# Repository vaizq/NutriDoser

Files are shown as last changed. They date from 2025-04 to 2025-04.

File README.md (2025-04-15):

# NutriDoser - Modular nutrient and pH controller for hydroponics

**NutriDoser** is and open-source prototype of an modular and extensible hydroponics reservoir controller.
Most devices on the market have limited capabilites on the number of nutrients that can be scheduled, but there's no limit with NutriDoser.
**DoserModules** can be daisy chained and controller detects how many of these modules there are and a scheduler takes care that no more than **n** parallel dosers are running.

> ⚠️ **Disclaimer:** This project is still at prototyping stage and should not be used without supervising.
 
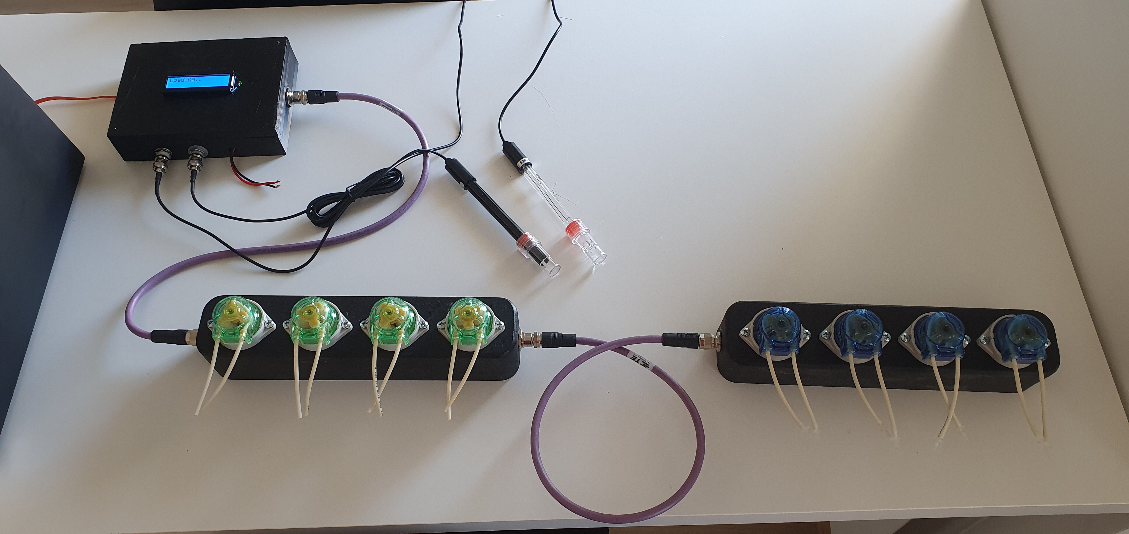
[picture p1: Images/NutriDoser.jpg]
NutriDoser

DoserModule pcb

---

## ✨ Key Features

- **Connect unlimited number of dosing pumps**
- **Web interface**
- **Custom PCB that's designed to use mostly basic parts from JLCPCB**
- **Automatic CAN termination**

---

## 🌐 Demo video
https://youtu.be/jbT3SvvVrZw

---

## ⚙️ Stack

- **C++** – Embedded code
- **Javascript + React** – Web interface
- **KiCad** – Hardware design
- **ESP32**
- **STM32**

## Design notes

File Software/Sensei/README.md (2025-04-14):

# Sensei - Heart of hydroponics reservoir automation

## Features
- Read pH and EC sensors
- Control NutriDosers trough DoserManager api
- LCD display
- Automatic controllers for pH and nutrients
- Wifi provisioning
- mqtt api

## Missing features

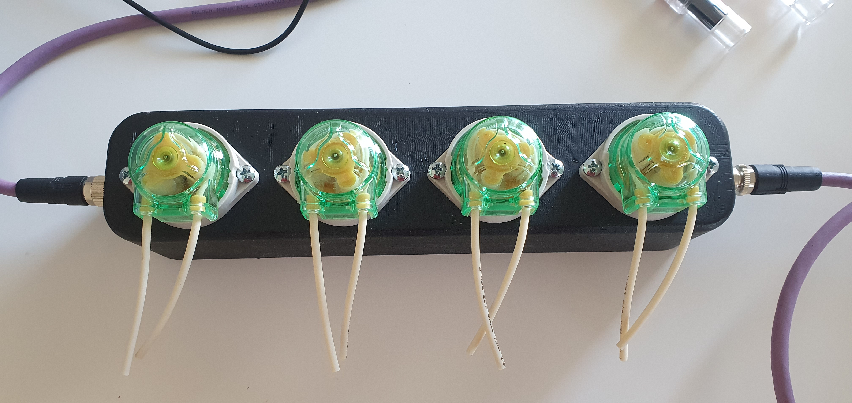
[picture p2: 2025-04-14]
Images/doserModule.jpg

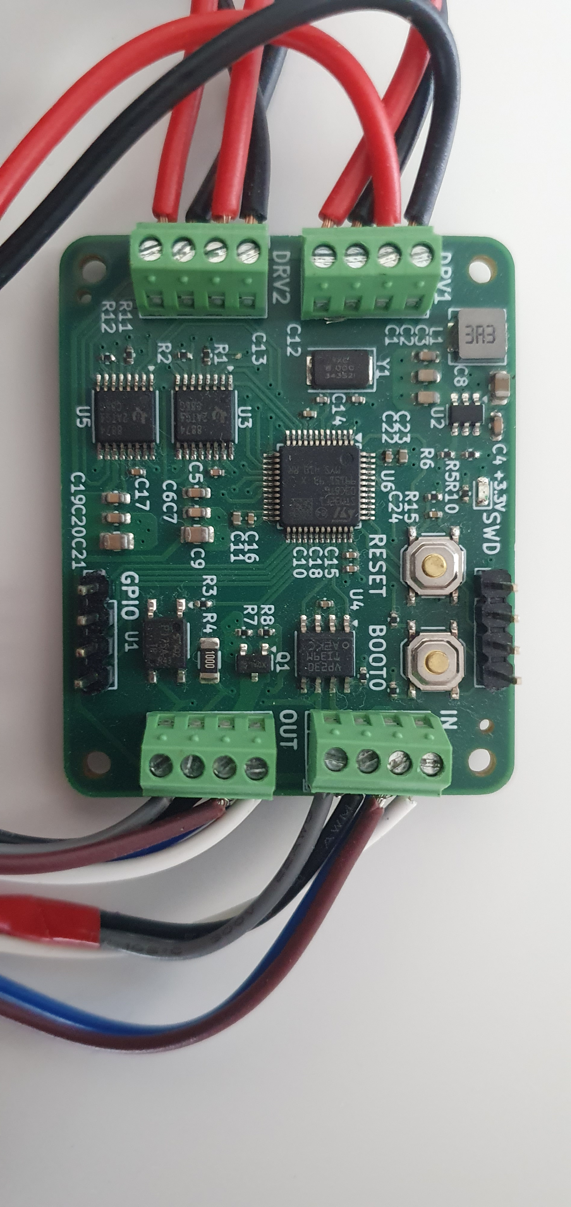
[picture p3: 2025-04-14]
Images/pcb.jpg

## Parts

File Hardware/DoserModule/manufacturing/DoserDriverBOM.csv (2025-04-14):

Comment | Designator | Footprint | LCSC
10uF | C1,C2 | Capacitor_SMD:C_0603_1608Metric | C96446
100nF | C10,C13,C15,C16,C18,C22,C24 | Capacitor_SMD:C_0402_1005Metric | C1525
10uF | C11,C23 | Capacitor_SMD:C_0402_1005Metric | C15525
30pF | C12,C14 | Capacitor_SMD:C_0402_1005Metric | C1570
100nF | C3,C4,C6,C7,C19,C20 | Capacitor_SMD:C_0603_1608Metric | C14663
22nF | C5,C17 | Capacitor_SMD:C_0402_1005Metric | C1532
47uF | C8 | Capacitor_SMD:C_0805_2012Metric | C16780
22uF | C9,C21 | Capacitor_SMD:C_0805_2012Metric | C45783
LED_Small | D1 | LED_SMD:LED_0603_1608Metric | C2286
3.3uH | L1 | Inductor_SMD:L_Sunlord_MWSA0402S | C408336
AO3400A | Q1 | Package_TO_SOT_SMD:SOT-23 | C20917
10kOhm | R1,R6,R11,R13,R14,R15 | Resistor_SMD:R_0402_1005Metric | C25744
1k5 Ohm | R10 | Resistor_SMD:R_0402_1005Metric | C25867
4.7kOhm | R2,R12 | Resistor_SMD:R_0402_1005Metric | C25900
470 Ohm | R3,R8 | Resistor_SMD:R_0402_1005Metric | C25117
100 Ohm | R4 | Resistor_SMD:R_1206_3216Metric | C17901
33.2kOhm | R5 | Resistor_SMD:R_0402_1005Metric | C122548
47kOhm | R7,R9 | Resistor_SMD:R_0402_1005Metric | C25792
SW_Push | SW1,SW2 | AutoDoser:SW_Push_1P1T_XKB_TS-1187A | C318884
TLP175A | U1 | Package_SO:MFSOP6-4_4.4x3.6mm_P1.27mm | C141522
TPS561208 | U2 | Package_TO_SOT_SMD:SOT-23-6 | C138335
DRV8874 | U3,U5 | AutoDoser:HTSSOP-16-1EP_4.4x5mm_P0.65mm_EP3.4x5mm_Mask2.46x2.31mm | C1855818
SN65HVD230 | U4 | Package_SO:SOIC-8_3.9x4.9mm_P1.27mm | C12084
STM32F103C8Tx | U6 | Package_QFP:LQFP-48_7x7mm_P0.5mm | C8734
Crystal | Y1 | Crystal:Crystal_SMD_5032-2Pin_5.0x3.2mm | C115962

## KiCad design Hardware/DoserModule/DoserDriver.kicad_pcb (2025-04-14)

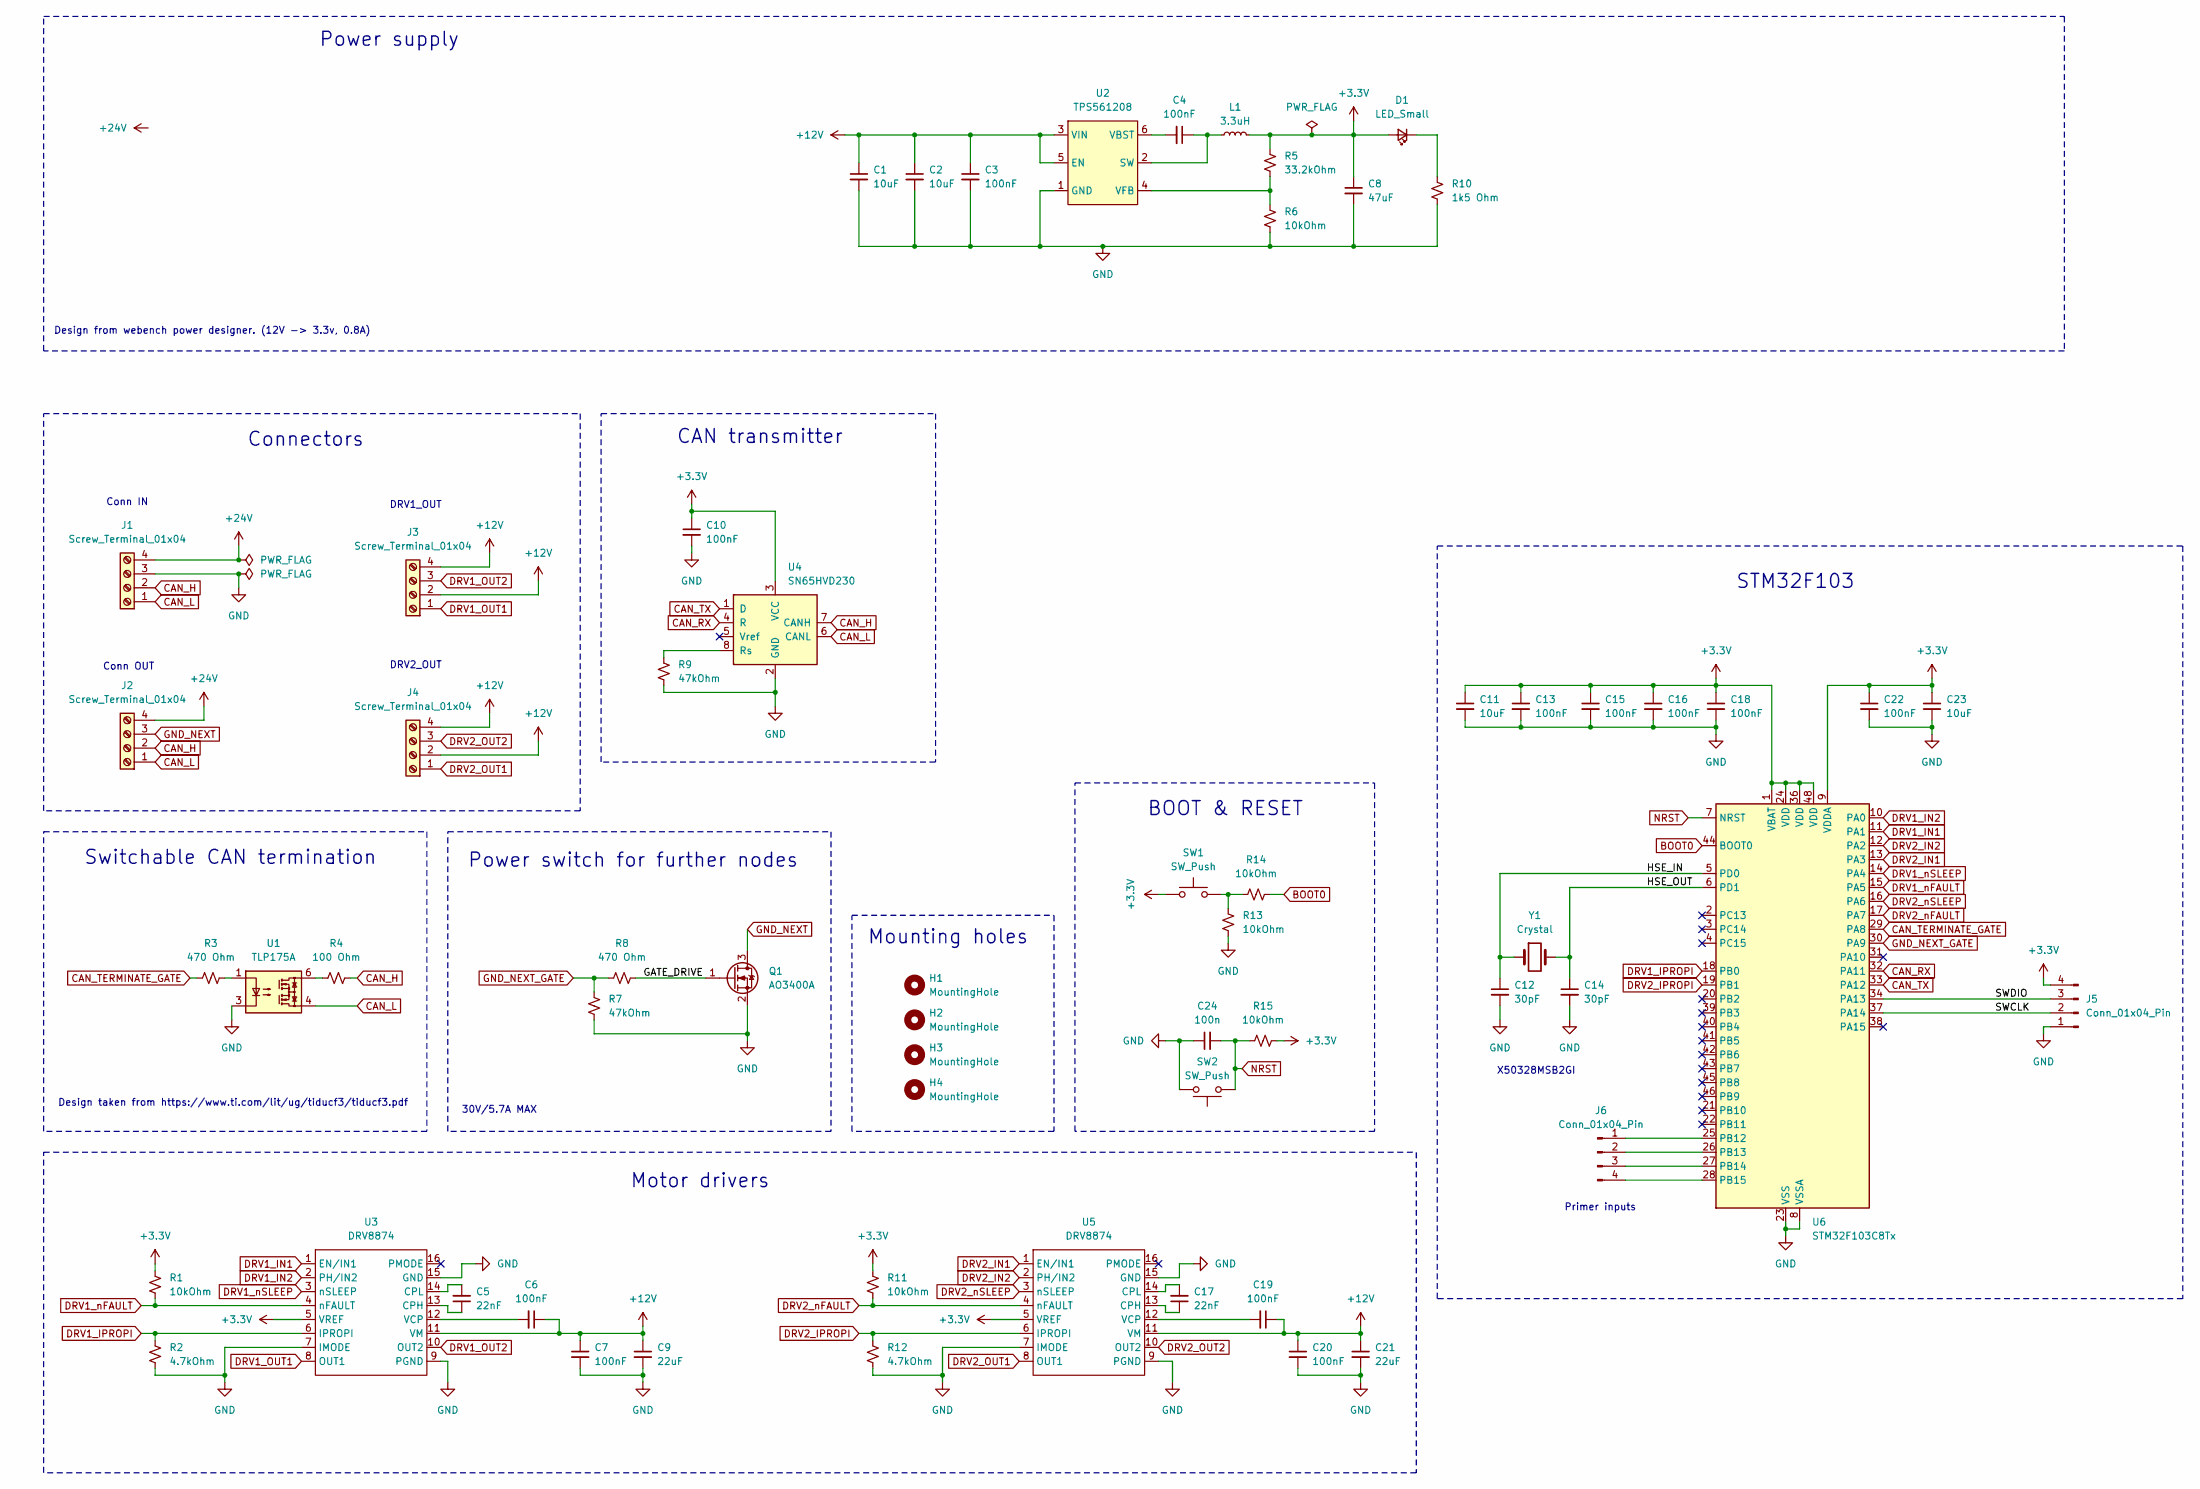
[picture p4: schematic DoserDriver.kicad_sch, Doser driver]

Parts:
C1, C2: 10uF; C_0603_1608Metric
C3, C4, C6, C7, C19, C20: 100nF; C_0603_1608Metric
C5, C17: 22nF; C_0402_1005Metric
C8: 47uF; C_0805_2012Metric
C9, C21: 22uF; C_0805_2012Metric
C10, C13, C15, C16, C18, C22: 100nF; C_0402_1005Metric
C11, C23: 10uF; C_0402_1005Metric
C12, C14: 30pF; C_0402_1005Metric
C24: 100n; C_0402_1005Metric
D1: LED_Small; LED_0603_1608Metric
H1, H2, H3, H4: MountingHole; MountingHole_2.2mm_M2
J1, J2, J3, J4: Screw_Terminal_01x04; TerminalBlock_Xinya_XY308-2.54-4P_1x04_P2.54mm_Horizontal
J5, J6: Conn_01x04_Pin; PinHeader_1x04_P2.54mm_Vertical
L1: 3.3uH; L_Sunlord_MWSA0402S
Q1: AO3400A; SOT-23
R1, R6, R11, R13, R14, R15: 10kOhm; R_0402_1005Metric
R2, R12: 4.7kOhm; R_0402_1005Metric
R3, R8: 470 Ohm; R_0402_1005Metric
R4: 100 Ohm; R_1206_3216Metric
R5: 33.2kOhm; R_0402_1005Metric
R7, R9: 47kOhm; R_0402_1005Metric
R10: 1k5 Ohm; R_0402_1005Metric
SW1, SW2: SW_Push; SW_Push_1P1T_XKB_TS-1187A
U1: TLP175A; MFSOP6-4_4.4x3.6mm_P1.27mm
U2: TPS561208; SOT-23-6
U3, U5: DRV8874; HTSSOP-16-1EP_4.4x5mm_P0.65mm_EP3.4x5mm_Mask2.46x2.31mm
U4: SN65HVD230; SOIC-8_3.9x4.9mm_P1.27mm
U6: STM32F103C8Tx; LQFP-48_7x7mm_P0.5mm
Y1: Crystal; Crystal_SMD_5032-2Pin_5.0x3.2mm

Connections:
+3.3V: C8.1, C10.1, C11.1, C13.1, C15.1, C16.1, C18.1, C22.1, C23.1, D1.2 (A), J5.4, L1.2, R1.1, R5.1, R11.1, R15.2, SW1.1, U3.5 (VREF), U4.3 (VCC), U5.5 (VREF), U6.1 (VBAT), U6.9 (VDDA), U6.24 (VDD), U6.36 (VDD), U6.48 (VDD)
/GATE_DRIVE: Q1.1 (G), R8.2
/HSE_IN: C12.1, U6.5 (PD0), Y1.1
/HSE_OUT: C14.1, U6.6 (PD1), Y1.2
/SWCLK: J5.2, U6.37 (PA14)
/SWDIO: J5.3, U6.34 (PA13)
BOOT0: R14.2, U6.44 (BOOT0)
CAN_H: J1.2, J2.2, R4.2, U4.7 (CANH)
CAN_L: J1.1, J2.1, U1.4, U4.6 (CANL)
CAN_RX: U4.4 (R), U6.32 (PA11)
CAN_TERMINATE_GATE: R3.2, U6.29 (PA8)
CAN_TX: U4.1 (D), U6.33 (PA12)
DRV1_IN1: U3.1 (EN/IN1), U6.11 (PA1)
DRV1_IN2: U3.2 (PH/IN2), U6.10 (PA0)
DRV1_IPROPI: R2.1, U3.6 (IPROPI), U6.18 (PB0)
DRV1_OUT1: J3.1, U3.8 (OUT1)
DRV1_OUT2: J3.3, U3.10 (OUT2)
DRV1_nFAULT: R1.2, U3.4 (nFAULT), U6.15 (PA5)
DRV1_nSLEEP: U3.3 (nSLEEP), U6.14 (PA4)
DRV2_IN1: U5.1 (EN/IN1), U6.13 (PA3)
DRV2_IN2: U5.2 (PH/IN2), U6.12 (PA2)
DRV2_IPROPI: R12.1, U5.6 (IPROPI), U6.19 (PB1)
DRV2_OUT1: J4.1, U5.8 (OUT1)
DRV2_OUT2: J4.3, U5.10 (OUT2)
DRV2_nFAULT: R11.2, U5.4 (nFAULT), U6.17 (PA7)
DRV2_nSLEEP: U5.3 (nSLEEP), U6.16 (PA6)
GND: C1.2, C2.2, C3.2, C7.2, C8.2, C9.2, C10.2, C11.2, C12.2, C13.2, C14.2, C15.2, C16.2, C18.2, C20.2, C21.2, C22.2, C23.2, C24.1, J1.3, J5.1, Q1.2 (S), R2.2, R6.2, R7.2, R9.1, R10.1, R12.2, R13.2, SW2.2, U1.3, U2.1 (GND), U3.7 (IMODE), U3.9 (PGND), U3.15 (GND), U4.2 (GND), U5.7 (IMODE), U5.9 (PGND), U5.15 (GND), U6.8 (VSSA), U6.23 (VSS), U6.35 (VSS), U6.47 (VSS)
GND_NEXT: J2.3, Q1.3 (D)
GND_NEXT_GATE: R7.1, R8.1, U6.30 (PA9)
NRST: C24.2, R15.1, SW2.1, U6.7 (NRST)
unnamed: D1.1 (K), R10.2
unnamed: J6.1, U6.25 (PB12)
unnamed: J6.2, U6.26 (PB13)
unnamed: J6.3, U6.27 (PB14)
unnamed: J6.4, U6.28 (PB15)
unnamed: R3.1, U1.1
unnamed: R4.1, U1.6
unnamed: R13.1, R14.1, SW1.2
unnamed: C4.1, L1.1, U2.2 (SW)
unnamed: C4.2, U2.6 (VBST)
unnamed: R5.2, R6.1, U2.4 (VFB)
unnamed: C5.1, U3.13 (CPH)
unnamed: C5.2, U3.14 (CPL)
unnamed: C6.2, U3.12 (VCP)
unnamed: R9.2, U4.8 (Rs)
unnamed: C17.1, U5.13 (CPH)
unnamed: C17.2, U5.14 (CPL)
unnamed: C19.2, U5.12 (VCP)

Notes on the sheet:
Conn OUT
Motor drivers
Mounting holes
X50328MSB2GI
Design from webench power designer. (12V -> 3.3v, 0.8A)
BOOT & RESET
30V/5.7A MAX
Connectors
Primer inputs
STM32F103
Conn IN
Switchable CAN termination
Design taken from https://www.ti.com/lit/ug/tiducf3/tiducf3.pdf
CAN transmitter
Power switch for further nodes
DRV1_OUT
Power supply
DRV2_OUT

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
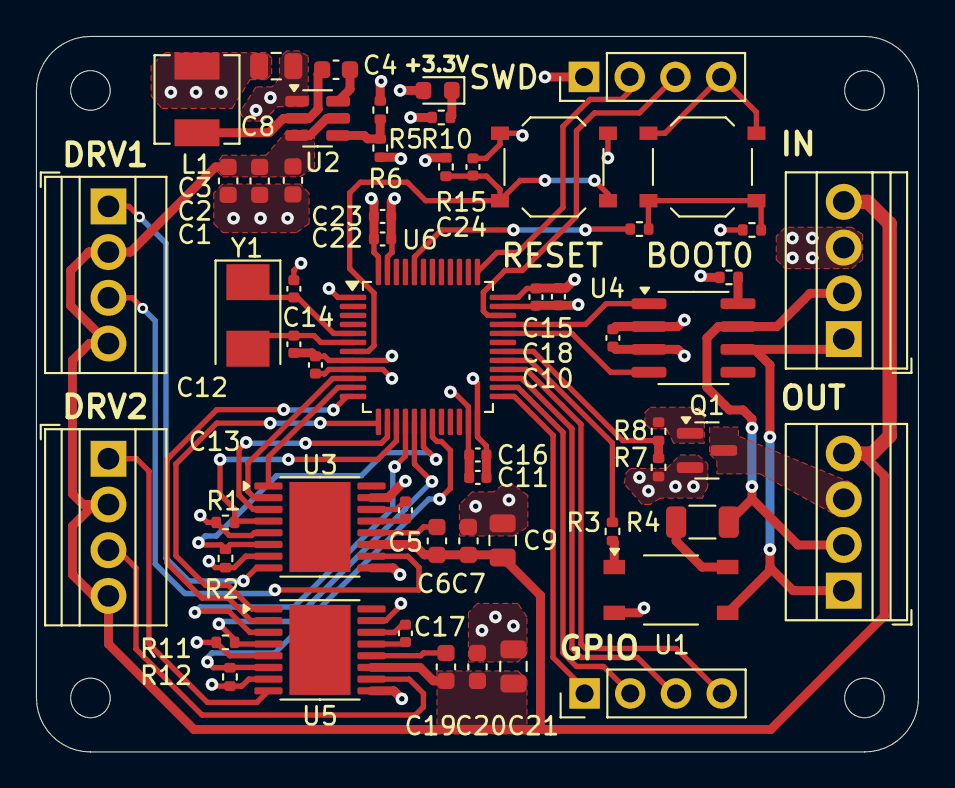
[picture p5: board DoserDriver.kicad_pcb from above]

Board: 4 copper layers, 49.0 x 39.8 mm, 61 parts (0 on the bottom side), 49 nets.

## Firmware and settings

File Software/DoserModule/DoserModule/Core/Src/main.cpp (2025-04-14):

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
/* Includes ------------------------------------------------------------------*/
#include "main.h"

/* USER CODE BEGIN Includes */
#include "app.hpp"
/* USER CODE END Includes */

ADC_HandleTypeDef hadc1;

CAN_HandleTypeDef hcan;

TIM_HandleTypeDef htim1;
TIM_HandleTypeDef htim2;

void SystemClock_Config(void);
static void MX_GPIO_Init(void);
static void MX_ADC1_Init(void);
static void MX_CAN_Init(void);
static void MX_TIM2_Init(void);
static void MX_TIM1_Init(void);
/**
  * @brief  The application entry point.
  * @retval int
  */
int main(void)
{

  /* MCU Configuration--------------------------------------------------------*/

  /* Reset of all peripherals, Initializes the Flash interface and the Systick. */
  HAL_Init();

  /* Configure the system clock */
  SystemClock_Config();

  /* Initialize all configured peripherals */
  MX_GPIO_Init();
  MX_ADC1_Init();
  MX_CAN_Init();
  MX_TIM2_Init();
  MX_TIM1_Init();
  /* USER CODE BEGIN 2 */

  // Start PWM channels
  HAL_TIM_PWM_Start(&htim2, TIM_CHANNEL_1);
  HAL_TIM_PWM_Start(&htim2, TIM_CHANNEL_2);
  HAL_TIM_PWM_Start(&htim2, TIM_CHANNEL_3);
  HAL_TIM_PWM_Start(&htim2, TIM_CHANNEL_4);

  // Start timer2 for steady_clock
  HAL_TIM_Base_Start_IT(&htim1);

  // Terminate CAN
  HAL_GPIO_WritePin(GPIOA, GPIO_PIN_8, GPIO_PIN_SET);

  if (HAL_CAN_Start(&hcan) != HAL_OK) {
      Error_Handler();
  }

  app_main(hcan);

  /* USER CODE END 2 */

  /* Infinite loop */
  /* USER CODE BEGIN WHILE */
  //while (1)
  {
    /* USER CODE END WHILE */

    /* USER CODE BEGIN 3 */
  }
  /* USER CODE END 3 */
}

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


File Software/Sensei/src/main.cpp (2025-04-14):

#include "App.hpp"
#include "mqtt.hpp"
#include <ArduinoJson.h>
#include <cstdio>

std::unique_ptr<App> gApp;

void apiRun() {
  ez::mqtt::Client client{"mqtt://5.61.89.44:1883"};

  client.subscribe("sensei/doser/on", [](const JsonDocument &doc) {
    const int id = doc["doserID"];
    if (auto doser = gDoserManager->lendDoser(id); doser) {
      if (doser->tryOn(doc["flowRate"]))
        gApp->runningDosers.push_back(std::move(*doser));
    }
  });

  client.subscribe("sensei/doser/off", [](const JsonDocument &doc) {
    std::erase_if(gApp->runningDosers,
                  [id = doc["doserID"]](const auto &doser) {
                    return doser.getId() == id;
                  });
  });

  client.subscribe("sensei/doserManager/reset",
                   []() { gApp->runningDosers.clear(); });

  client.subscribe("sensei/pHSensor/calibrate", [](const JsonDocument &doc) {
    gApp->pHSensor->calibrate(doc["target"]);
  });

  client.subscribe("sensei/ecSensor/calibrate", [](const JsonDocument &doc) {
    gApp->ecSensor->calibrate(doc["target"]);
  });

  client.subscribe("sensei/pHSensor/factoryReset",
                   []() { gApp->pHSensor->factoryReset(); });

  client.subscribe("sensei/ecSensor/factoryReset",
                   []() { gApp->ecSensor->factoryReset(); });

  client.subscribe("sensei/pHController/start", [](const JsonDocument &doc) {
    auto config = doc["config"].as<PhController::Config>();
    gApp->pHController->start(config);
  });

  client.subscribe(
      "sensei/nutrientController/start", [](const JsonDocument &doc) {
        auto config = doc["config"].as<NutrientController::Config>();
        gApp->nutrientController->start(config);
      });

  client.subscribe("sensei/pHController/stop",
                   []() { gApp->pHController->stop(); });

  client.subscribe("sensei/nutrientController/stop",
                   []() { gApp->nutrientController->stop(); });

  client.start();

  for (char buf[1024];;) {
    const App::Status status = gApp->status();

    JsonDocument doc;
    convertToJson(status, doc);

    size_t n = serializeJson(doc, buf);
    client.publish("sensei/status", {buf, n});

    vTaskDelay(pdMS_TO_TICKS(500));
  }
}

extern "C" void app_main(void) {
  gApp = std::make_unique<App>();
  apiRun();
}

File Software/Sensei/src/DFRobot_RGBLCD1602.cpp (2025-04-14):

/*!
 * @file DFRobot_RGBLCD1602.cpp
 * @brief DFRobot_RGBLCD1602 class infrastructure, the implementation of basic methods
 * @copyright	Copyright (c) 2010 DFRobot Co.Ltd (http://www.dfrobot.com)
 * @licence     The MIT License (MIT)
 * @maintainer [yangfeng](feng.yang@dfrobot.com)
 * @version  V1.0
 * @date  2021-09-24
 * @url https://github.com/DFRobot/DFRobot_RGBLCD1602
 */

#include <stdio.h>
#include <string.h>
#include "freertos/FreeRTOS.h"


#include "DFRobot_RGBLCD1602.h"

const uint8_t color_define[4][3] = 
{
    {255, 255, 255},            // white
    {255, 0, 0},                // red
    {0, 255, 0},                // green
    {0, 0, 255},                // blue
};

/*******************************public*******************************/
DFRobot_RGBLCD1602::DFRobot_RGBLCD1602(uint8_t RGBAddr,uint8_t lcdCols,uint8_t lcdRows,uint8_t lcdAddr)
{
  _lcdAddr = lcdAddr;
  _RGBAddr = RGBAddr;
  _cols = lcdCols;
  _rows = lcdRows;
}

void DFRobot_RGBLCD1602::init()
{
    i2c_device_config_t cfg = {
        .dev_addr_length = I2C_ADDR_BIT_LEN_7,
        .device_address = _lcdAddr,
        .scl_speed_hz = 100000,
    };
    ESP_ERROR_CHECK(i2c_master_bus_add_device(i2c::bus, &cfg, &lcd));

    cfg.device_address = _RGBAddr;

    ESP_ERROR_CHECK(i2c_master_bus_add_device(i2c::bus, &cfg, &rgb));


  if(_RGBAddr == (0x60)){
    REG_RED   =      0x04;
    REG_GREEN =      0x03;
    REG_BLUE  =      0x02;
    REG_ONLY  =      0x02 ;
  } else if(_RGBAddr == (0x60>>1)){
    REG_RED      =   0x06 ;       // pwm2
    REG_GREEN    =   0x07 ;       // pwm1
    REG_BLUE     =   0x08 ;       // pwm0
    REG_ONLY     =   0x08 ;
  } else if(_RGBAddr == (0x6B)){
    REG_RED      =   0x06 ;       // pwm2
    REG_GREEN    =   0x05 ;       // pwm1
    REG_BLUE     =   0x04 ;       // pwm0
    REG_ONLY     =   0x04 ; 
  } else if(_RGBAddr == (0x2D)){
    REG_RED      =   0x01 ;       // pwm2
    REG_GREEN    =   0x02 ;       // pwm1
    REG_BLUE     =   0x03 ;       // pwm0
    REG_ONLY     =   0x01 ; 
  }
  _showFunction = LCD_4BITMODE | LCD_1LINE | LCD_5x8DOTS;
  begin(_rows);
  clear();
}

void DFRobot_RGBLCD1602::clear()
{
    command(LCD_CLEARDISPLAY);        // clear display, set cursor position to zero
    vTaskDelay(pdMS_TO_TICKS(10));          // this command takes a long time!
}

void DFRobot_RGBLCD1602::home()
{
    command(LCD_RETURNHOME);        // set cursor position to zero
    vTaskDelay(pdMS_TO_TICKS(2));        // this command takes a long time!
}

void DFRobot_RGBLCD1602::noDisplay()
{
    _showControl &= ~LCD_DISPLAYON;
    command(LCD_DISPLAYCONTROL | _showControl);
}

void DFRobot_RGBLCD1602::display() {
    _showControl |= LCD_DISPLAYON;
    command(LCD_DISPLAYCONTROL | _showControl);
}

void DFRobot_RGBLCD1602::stopBlink()
{
    _showControl &= ~LCD_BLINKON;
    command(LCD_DISPLAYCONTROL | _showControl);
}
void DFRobot_RGBLCD1602::blink()
{
    _showControl |= LCD_BLINKON;
    command(LCD_DISPLAYCONTROL | _showControl);
}

void DFRobot_RGBLCD1602::noCursor()
{
    _showControl &= ~LCD_CURSORON;
    command(LCD_DISPLAYCONTROL | _showControl);
}

void DFRobot_RGBLCD1602::cursor() {
    _showControl |= LCD_CURSORON;
    command(LCD_DISPLAYCONTROL | _showControl);
}

void DFRobot_RGBLCD1602::scrollDisplayLeft(void)
{
    command(LCD_CURSORSHIFT | LCD_DISPLAYMOVE | LCD_MOVELEFT);
}

void DFRobot_RGBLCD1602::scrollDisplayRight(void)
{
    command(LCD_CURSORSHIFT | LCD_DISPLAYMOVE | LCD_MOVERIGHT);
}

void DFRobot_RGBLCD1602::leftToRight(void)
{
    _showMode |= LCD_ENTRYLEFT;
    command(LCD_ENTRYMODESET | _showMode);
}

void DFRobot_RGBLCD1602::rightToLeft(void)
{
    _showMode &= ~LCD_ENTRYLEFT;
    command(LCD_ENTRYMODESET | _showMode);
}

void DFRobot_RGBLCD1602::noAutoscroll(void)
{
    _showMode &= ~LCD_ENTRYSHIFTINCREMENT;
    command(LCD_ENTRYMODESET | _showMode);
}

void DFRobot_RGBLCD1602::autoscroll(void)
{
    _showMode |= LCD_ENTRYSHIFTINCREMENT;
    command(LCD_ENTRYMODESET | _showMode);
}

void DFRobot_RGBLCD1602::customSymbol(uint8_t location, uint8_t charmap[])
{

    location &= 0x7; // we only have 8 locations 0-7
    command(LCD_SETCGRAMADDR | (location << 3));
    
    
    uint8_t data[9];
    data[0] = 0x40;
    for(int i=0; i<8; i++)
    {
        data[i+1] = charmap[i];
    }
    send(data, 9);
}

void DFRobot_RGBLCD1602::setCursor(uint8_t col, uint8_t row)
{

    col = (row == 0 ? col|0x80 : col|0xc0);
    uint8_t data[3] = {0x80, col};

    send(data, 2);
}

void DFRobot_RGBLCD1602::setRGB(uint8_t r, uint8_t g, uint8_t b)
{
  uint16_t temp_r,temp_g,temp_b;
  if(_RGBAddr == 0x60>>1){
    temp_r = (uint16_t)r*192/255;
    temp_g = (uint16_t)g*192/255;
    temp_b = (uint16_t)b*192/255;
    setReg(REG_RED, temp_r);
    setReg(REG_GREEN, temp_g);
    setReg(REG_BLUE, temp_b);
  } else{
    setReg(REG_RED, r);
    setReg(REG_GREEN, g);
    setReg(REG_BLUE, b);
    if(_RGBAddr == 0x6B){
      setReg(0x07, 0xFF);
    }
  }

}

void DFRobot_RGBLCD1602::setColor(uint8_t color)
{
    if(color > 3)return ;
    setRGB(color_define[color][0], color_define[color][1], color_define[color][2]);
}


inline size_t DFRobot_RGBLCD1602::write(uint8_t value)
{

    uint8_t data[3] = {0x40, value};
    send(data, 2);
    return 1; // assume sucess
}

inline void DFRobot_RGBLCD1602::command(uint8_t value)
{
    uint8_t data[3] = {0x80, value};
    send(data, 2);
}



void DFRobot_RGBLCD1602::setBacklight(bool mode){
	if(mode){
		setColorWhite();		// turn backlight on
	}else{
		closeBacklight();		// turn backlight off
	}
}
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

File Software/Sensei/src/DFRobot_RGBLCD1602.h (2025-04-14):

/*!
 * @file DFRobot_RGBLCD1602.h
 * @brief DFRobot_RGBLCD1602 class infrastructure
 * @copyright	Copyright (c) 2010 DFRobot Co.Ltd (http://www.dfrobot.com)
 * @licence     The MIT License (MIT)
 * @maintainer [yangfeng](feng.yang@dfrobot.com)
 * @version  V1.0
 * @date  2021-09-24
 * @url https://github.com/DFRobot/DFRobot_RGBLCD1602
 */

#ifndef __DFRobot_RGBLCD1602_H__
#define __DFRobot_RGBLCD1602_H__
#include <inttypes.h>
#include <stdio.h>
#include <string.h>
#include "i2c.hpp"

/*!
 *  @brief Device I2C Arress
 */
#define LCD_ADDRESS     (0x7c>>1)

/*!
 *  @brief color define
 */ 
#define WHITE           0
#define RED             1
#define GREEN           2
#define BLUE            3



#define REG_MODE1       0x00
#define REG_MODE2       0x01
#define REG_OUTPUT      0x08

/*!
 *  @brief commands
 */
#define LCD_CLEARDISPLAY 0x01
#define LCD_RETURNHOME 0x02
#define LCD_ENTRYMODESET 0x04
#define LCD_DISPLAYCONTROL 0x08
#define LCD_CURSORSHIFT 0x10
#define LCD_FUNCTIONSET 0x20
#define LCD_SETCGRAMADDR 0x40
#define LCD_SETDDRAMADDR 0x80

/*!
 *  @brief flags for display entry mode
 */
#define LCD_ENTRYRIGHT 0x00
#define LCD_ENTRYLEFT 0x02
#define LCD_ENTRYSHIFTINCREMENT 0x01
#define LCD_ENTRYSHIFTDECREMENT 0x00

/*!
 *  @brief flags for display on/off control
 */
#define LCD_DISPLAYON 0x04
#define LCD_DISPLAYOFF 0x00
#define LCD_CURSORON 0x02
#define LCD_CURSOROFF 0x00
#define LCD_BLINKON 0x01
#define LCD_BLINKOFF 0x00

/*!
 *  @brief flags for display/cursor shift
 */
#define LCD_DISPLAYMOVE 0x08
#define LCD_CURSORMOVE 0x00
#define LCD_MOVERIGHT 0x04
#define LCD_MOVELEFT 0x00

/*!
 *  @brief flags for function set
 */
#define LCD_8BITMODE 0x10
#define LCD_4BITMODE 0x00
#define LCD_2LINE 0x08
#define LCD_1LINE 0x00
#define LCD_5x10DOTS 0x04
#define LCD_5x8DOTS 0x00

class DFRobot_RGBLCD1602
{

public:
  /**
   * @fn DFRobot_RGBLCD1602
   * @brief Constructor
   */
  DFRobot_RGBLCD1602(uint8_t RGBAddr,uint8_t lcdCols=16,uint8_t lcdRows=2, uint8_t lcdAddr=LCD_ADDRESS);

  /**
   * @fn init
   * @brief initialize the LCD and master IIC
   */ 
  void init();

  /**
   * @fn clear
   * @brief clear the display and return the cursor to the initial position (position 0)
   */
  void clear();

  /**
   * @fn home
   * @brief return the cursor to the initial position (0,0)
   */
  void home();

    /**
     * @fn noDisplay
     * @brief Turn off the display
     */
  void noDisplay();

  /**
   * @fn display
   * @brief Turn on the display
   */
  void display();

  /**
   * @fn stopBlink
   * @brief Turn  off the blinking showCursor
   */
  void stopBlink();

  /**
   * @fn blink
   * @brief Turn on  the blinking showCursor
   */
  void blink();

  /**
   * @fn noCursor
   * @brief Turn off the underline showCursor 
   */
  void noCursor();

  /**
   * @fn cursor
   * @brief Turn on the underline showCursor 
   */
  void cursor();

  /**
   * @fn scrollDisplayLeft
   * @brief scroll left to display
   */
  void scrollDisplayLeft();

  /**
   * @fn scrollDisplayRight
   * @brief scroll right to display
   */
  void scrollDisplayRight();
 
  /**
   * @fn leftToRight
   * @brief This is for text that flows Left to Right
   */
  void leftToRight();
 
  /**
   * @fn rightToLeft
   * @brief This is for text that flows Right to Left
   */
  void rightToLeft();

  /**
   * @fn noAutoscroll
   * @brief This will 'left justify' text from the showCursor
   */
  void noAutoscroll();
 
  /**
   * @fn autoscroll
   * @brief This will 'right justify' text from the showCursor
   */
  void autoscroll();
   
  /**
   * @fn customSymbol
   * @brief Allows us to fill the first 8 CGRAM locations with custom characters
   * @param location substitute character range (0-7)
   * @param charmap  character array the size is 8 bytes
   */
  void customSymbol(uint8_t location, uint8_t charmap[]);

  /**
   * @fn setCursor
   * @brief set cursor position
   * @param col columns optional range 0-15
   * @param row rows optional range 0-1，0 is the first row, 1 is the second row
   */
  void setCursor(uint8_t col, uint8_t row);
  
  /**
   * @fn setRGB
   * @brief set RGB
   * @param r  red   range(0-255)
   * @param g  green range(0-255)
   * @param b  blue  range(0-255)
   */
  void setRGB(uint8_t r, uint8_t g, uint8_t b);

  /**
   * @fn setPWM
   * @brief set backlight PWM output
   * @param color  backlight color  Preferences：REG_RED\REG_GREEN\REG_BLUE
   * @param pwm  color intensity   range(0-255)
   */
  void setPWM(uint8_t color, uint8_t pwm){setReg(color, pwm); if(_RGBAddr==0x6B){setReg(0x07, pwm);}}      // set pwm

  /**
   * @fn setColor
   * @brief backlight color
   * @param color  backlight color  Preferences： WHITE\RED\GREEN\BLUE
   */
  void setColor(uint8_t color);

  /**
   * @fn closeBacklight
   * @brief close the backlight
   */
  void closeBacklight(){setRGB(0, 0, 0);}

  /**
   * @fn setColorWhite
   * @brief set the backlight to white
   */
  void setColorWhite(){setRGB(255, 255, 255);}

  /**
   * @fn write
   * @brief write character
   * @param data the written data
   */
  virtual size_t write(uint8_t data);

  template <typename ...T>
  void print(const char* format, const T... args) {
    char buf[32];
    snprintf(buf, sizeof(buf), format, args...);
    for (int i = 0; buf[i] != 0; ++i) {
      write(buf[i]);
    }
  }

  /**
   * @fn command
   * @brief send command
   * @param data the sent command
   */
  void command(uint8_t data);

  /**
   * @fn setBacklight
   * @brief set the backlight
   * @param mode  true indicates the backlight is turned on and set to white, false indicates the backlight is turned off
   */
  void setBacklight(bool mode);
  
private:
  /**
   * @fn begin
   * @brief the initialization function
   * @param row rows optional range 0-1，0 is the first row, 1 is the second row
   * @param charSize  character size LCD_5x8DOTS\LCD_5x10DOTS
   */
  void begin(uint8_t rows, uint8_t charSize = LCD_5x8DOTS);

  /**
   * @fn send
   * @brief set cursor
   * @param data the data to send
   * @param len length of the data
   */
  void send(uint8_t *data, uint8_t len);

  /**
   * @fn setReg
   * @brief Configure related registers
   * @param addr  The address of the register to be operated on
   * @param data  The data to be written
   */
  void setReg(uint8_t addr, uint8_t data);

  uint8_t _showFunction;
  uint8_t _showControl;
  uint8_t _showMode;
  uint8_t _initialized;
  uint8_t _numLines,_currLine;
  uint8_t _lcdAddr;
  uint8_t _RGBAddr;
  uint8_t _cols;
  uint8_t _rows;
  i2c_master_dev_handle_t lcd;
  i2c_master_dev_handle_t rgb;
public:
  uint8_t REG_RED      =   0 ;       // pwm2
  uint8_t REG_GREEN    =   0 ;       // pwm1
  uint8_t REG_BLUE     =   0 ;       // pwm0
  uint8_t REG_ONLY     =   0 ;       // pwm0
};

#endif

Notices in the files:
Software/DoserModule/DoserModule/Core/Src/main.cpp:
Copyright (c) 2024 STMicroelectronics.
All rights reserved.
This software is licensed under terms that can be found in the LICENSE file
